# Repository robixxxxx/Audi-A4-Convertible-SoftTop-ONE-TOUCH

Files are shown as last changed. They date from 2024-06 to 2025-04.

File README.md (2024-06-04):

# Audi A4 Convertible Soft Top ONE TOUCH Module
## 1. Basic module for opening the folding roof of an audi a4 convertible by double-clicking the button.

## 2. (work in progress) Module for opening the folding roof on audi a4 convertible by double-clicking the button or using the original remote control. The module is to have the ability to change the maximum speed at which the roof can be opened/closed.

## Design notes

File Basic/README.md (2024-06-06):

# Audi A4 Convertible Soft Top Basic ONE TOUCH Module
This project provides an Arduino-based solution to control the roof of an Audi A4 Cabrio using original roof button. The provided code manages the open and close operations of the roof by double-click .

## 1. Hardware Requirements
- Arduino board (e.g., Arduino Uno)
- Two BC547 transistors
- Two 1kOhm resistors
- Connecting wires
- Male goldpin 2x3
- Female golpin 2x3

### The wiring diagram is available in the schematics folder

## 2. Software

### Installation
1. Install the [Visual Studio Code](https://code.visualstudio.com) with [PlatformIO](https://platformio.org) extension or [Arduino IDE](https://www.arduino.cc/en/software)
2. Connect your Arduino board to your computer via USB.
3. Open IDE and clone repository or create a new project and copy the code
5. Verify and upload the code to your Arduino

### Functionality
- Button Debouncing: Prevents false triggering of button presses.
- Button Sequence Handling: Manages the sequence of button presses to ensure the correct operation of the roof.
- Safety Timeout: Automatically stops the roof if it moves beyond the predefined time.
### Usage
- Opening the Roof: Press the "Open" button twice within 800ms to start opening the roof. Pressing the button more than twice will stop the roof.
- Closing the Roof: Press the "Close" button twice within 800ms to start closing the roof. Pressing the button more than twice will stop the roof.
## Ensure the vehicle is parked and it is safe to operate the roof before using this system.

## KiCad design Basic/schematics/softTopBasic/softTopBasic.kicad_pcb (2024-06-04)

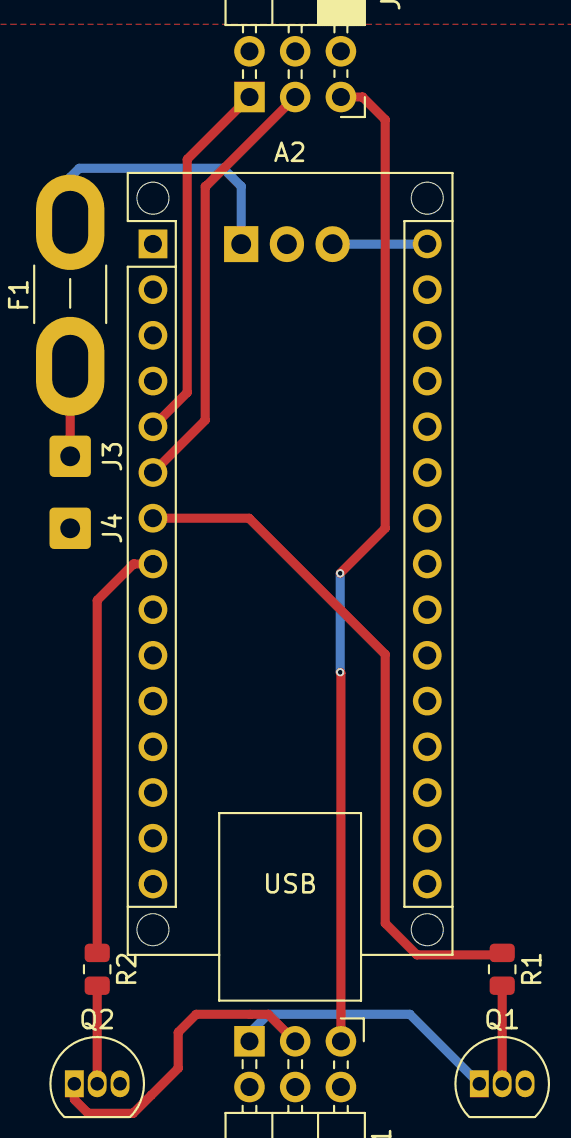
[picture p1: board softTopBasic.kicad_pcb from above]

Board: 2 copper layers, 11 parts (1 on the bottom side), 13 nets.

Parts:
A2: Arduino_Nano_Every; Arduino_Nano_WithMountingHoles
F1: 150mA; Fuse_Blade_Mini_directSolder
J1: Original Plug; PinHeader_2x03_P2.54mm_Horizontal
J2: New Switch Plug; PinSocket_2x03_P2.54mm_Horizontal
J3: +12V; SolderWire-0.5sqmm_1x01_D0.9mm_OD2.3mm
J4: GND; SolderWire-0.5sqmm_1x01_D0.9mm_OD2.3mm
Q1, Q2: BC547; TO-92_Inline
R1, R2: 1k; R_0805_2012Metric
U1: LM7805_TO220; TO-220-3_Vertical

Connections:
+5V: A2.30 (VIN), U1.3 (VO)
+12V: F1.2, U1.1 (VI)
/INPUT1: A2.5 (D2), J2.1
/INPUT2: A2.6 (D3), J2.2
/Inputs/button illumination: J1.3, J2.3
/OUTPUT1: A2.7 (D4), R1.1
/OUTPUT2: A2.8 (D5), R2.1
GND: A2.4 (GND), A2.29 (GND), J1.4, J2.4, J4.1, Q1.3 (E), Q2.3 (E), U1.2 (GND)
unnamed: J1.1, Q1.1 (C)
unnamed: J1.2, Q2.1 (C)
unnamed: F1.1, J3.1
unnamed: Q1.2 (B), R1.2
unnamed: Q2.2 (B), R2.2

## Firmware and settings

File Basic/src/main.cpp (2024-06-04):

#include <Arduino.h>
#include <avr/wdt.h>

//definition of delays
const unsigned long roofOpenTime = 30000;
const unsigned long delayBetweenClick = 800;

unsigned long debounceDelay = 50;

//definition of input/output pins
const int inputPinOpen = 2;
const int inputPinClose = 3;
const int outputPinOpen = 4; 
const int outputPinClose = 5;
volatile bool openButtonPressed = false;
volatile bool closeButtonPressed = false; 

//buttons sequence state
unsigned int clicksOpen = 0;
unsigned int clicksClose = 0;
unsigned long lastOpenPressed = 0;
unsigned long lastClosePressed = 0;

//roof state
bool roofMoves = false;
unsigned long runTime = 0;

void chceckRoofVars();
void initRoof();
void closeButtonISR();
void openButtonISR();
void checkButtonsState();
void checkButtonSequenceTime();
void roofCloseSequence();
void roofOpenSequence();
void checkMoveTime();

void setup() {
  wdt_enable(WDTO_15MS);
  initRoof();  
}

void loop() {
  wdt_reset();
  chceckRoofVars();
}

void checkMoveTime(){
    if((millis()-runTime>roofOpenTime)&&roofMoves){ //if roof was opening for assigned roofOpenTime stop the roof and reset click sequences
    digitalWrite(outputPinOpen, LOW);
    clicksOpen = 0;
    digitalWrite(outputPinClose, LOW);
    clicksClose = 0;
    roofMoves = false;
    }
}

void roofOpenSequence(){
      clicksOpen++; //increase open sequence
    clicksClose = 0; //reset close sequence
    digitalWrite(outputPinClose, LOW); //stops roof if it's closing
    if(clicksOpen==2){ //if clicks sequence == 2
      digitalWrite(outputPinOpen, HIGH); //open roof
      runTime = millis();
      roofMoves = true;
    }
    if(clicksOpen>2){ //if clicks sequence is >2 stop roof and reset clicks sequence
      clicksOpen=0;
      digitalWrite(outputPinOpen, LOW); // Włączenie pierwszej diody LED
      roofMoves = false;
    }
    lastOpenPressed = millis(); //remember last open button click time
    openButtonPressed = false;
}

void roofCloseSequence(){
  clicksClose++;
    clicksOpen = 0;
    digitalWrite(outputPinOpen, LOW);
    if (clicksClose==2) { 
      digitalWrite(outputPinClose, HIGH); 
      runTime = millis();
      roofMoves = true;
    }
    if (clicksClose>2) {
      clicksClose=0;
      
      digitalWrite(outputPinClose, LOW);
      roofMoves = false;
    }
    closeButtonPressed = false;
    lastClosePressed = millis();
}

void checkButtonSequenceTime(){
    if((millis()-lastOpenPressed>delayBetweenClick)&&!roofMoves)// if open button wasn't pressed for assigned time reset click squence
    clicksOpen=0;
    if((millis()-lastClosePressed>delayBetweenClick)&&!roofMoves)
    clicksClose=0;
}

void checkButtonsState(){
    if(openButtonPressed) {
        roofOpenSequence();
    }
    if (closeButtonPressed) {
        roofCloseSequence();
    }
}

void openButtonISR() {
  static unsigned long last_interrupt_time = 0;
  unsigned long interrupt_time = millis();
  if(interrupt_time - last_interrupt_time > debounceDelay)
    openButtonPressed = !digitalRead(inputPinOpen);
  last_interrupt_time = interrupt_time;
}

void closeButtonISR() {
  static unsigned long last_interrupt_time = 0;
  unsigned long interrupt_time = millis();
  if(interrupt_time - last_interrupt_time > debounceDelay){
    closeButtonPressed = !digitalRead(inputPinClose);      
  }                                                                                                                                                                                 
  last_interrupt_time = interrupt_time;
}

void initRoof(){
  pinMode(inputPinOpen, INPUT_PULLUP);
  pinMode(inputPinClose, INPUT_PULLUP); 
  pinMode(outputPinOpen, OUTPUT); 
  pinMode(outputPinClose, OUTPUT);
  digitalWrite(outputPinOpen, LOW);
  digitalWrite(outputPinClose, LOW);
  attachInterrupt(digitalPinToInterrupt(inputPinOpen), openButtonISR, CHANGE); // Assinging interrupt for open button
  attachInterrupt(digitalPinToInterrupt(inputPinClose), closeButtonISR, CHANGE); // Assinging interrupt for close button
}

void chceckRoofVars(){
    checkButtonsState();
    checkMoveTime();
    checkButtonSequenceTime();
}

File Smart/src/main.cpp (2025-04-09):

#include <Arduino.h>
// #include <wdt.h>
#include <roof.h>
#include <EEPROM.h>
#include <ArduinoOTA.h>
#include <canModule.h>
#include <esp_task_wdt.h>
// #include <www.h>
#define WDT_TIMEOUT 3
#define SERIAL 0

long baudrate = 100E3;

uint8_t CAN_TX_PIN = 5;
uint8_t CAN_RX_PIN = 4;
uint8_t CS_PIN = 8;
CanModule * CAN0, * CAN1;
packet_t packet;
void setup() {
  esp_task_wdt_init(WDT_TIMEOUT, true); 
  esp_task_wdt_add(NULL);
  CAN0 = new CanModule(&baudrate, &CAN_RX_PIN, &CAN_TX_PIN);
  CAN1 = new CanModule(&baudrate, &CS_PIN);
  #if SERIAL==1
    Serial.begin(250000);
    while (!Serial) {
    ; // wait for serial port to connect.
    }
  #endif 
}

void loop() {
  esp_task_wdt_reset();
  packet = CAN0->receive();
  if(packet.id == 0x381){

  }
  else if(packet.id!=0xFF){
    CAN1->sendPacketToCan(&packet);
  }
  packet = CAN1->receive();
  if(packet.id!=0xFF){
    CAN0->sendPacketToCan(&packet);
  }
  
  
  // ESP.wdtFeed(); // reset watchdog
  chceckRoofVars();
  // dnsServer.processNextRequest();
}

// void initEEPROM(){
//   size_t eepromSize = sizeof(NetworkParameters);
//   eepromSize+=sizeof(CANBUSParameters);
//   EEPROM.begin(eepromSize);
//   readFromEEPROM(paramNetwork);
//   readFromEEPROM(paramCAN);

// }
// void readFromEEPROM(NetworkParameters &data) {
//     EEPROM.get(0, data);
// }
// void readFromEEPROM(CANBUSParameters &data) {
//     EEPROM.get(sizeof(NetworkParameters), data);
// }

// void writeToEEPROM(const NetworkParameters &data) {
//     EEPROM.put(0, data);
// }
// void writeToEEPROM(const CANBUSParameters &data) {
//     EEPROM.put(sizeof(NetworkParameters), data);
// }
